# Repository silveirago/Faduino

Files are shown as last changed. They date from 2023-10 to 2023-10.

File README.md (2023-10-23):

# Faduino

The Faduino is a DIY MIDI controller inspired in the Presonus Faderport. It has one motorized fader, a rotary encoder and several silicone buttons, plus two PCBs. One PCB contains all the pads, which are triggered by the silicone buttons, addressable LEDs, a multiplexer, and some other stuff.
It can control natively any DAW, because it works with the MCU - or Mackie - Protocol, so it can work even in Pro Tools. With its motorized fader, rotary encoder, and LED buttons, you can change the track and the parameters in DAW get updated in the controller, moving the motorized fader, changing LEDs, etc.
With the Faduino you can control any channel strip, transport, and many other things in the DAW!

Complete Tutorial: Nerd Musician Pro (all the courses): https://go.musiconerd.com/nerd-musician-pro
Tutorialo Completo (Português): Fazendo Música com Arduino: https://go.musiconerd.com/fazendo-musica-com-arduino
Watch the YT video: https://youtu.be/M8krxn_5pIs

by Gustavo Silveira
gustavosilveira@musiconerd.com

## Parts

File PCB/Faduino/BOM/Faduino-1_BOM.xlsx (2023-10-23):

Comment | Designator | Footprint | LCSC Part #
100nF Unpolarized capacitor, small symbol | C1,C2,C3,C4,C5,C6,C7,C8,C9,C10,C11,C12,C13,C14,C15,C16,C17,C18,C19,C20,C21,C22,C23,C24 | C_0603_1608Metric | C14663
100nF Unpolarized capacitor, small symbol | C_mux_1,C_mux_2 | C_0603_1608Metric | C14663
100nF | C_pwr_2 | C_0603_1608Metric | C14663
L7805 Positive 1.5A 35V Linear Regulator, Fixed Output 5V, TO-220/TO-263/TO-252 | Tension_reg1 | TO-263-2 | C15077
330nF | C_pwr_1 | C_0603_1608Metric | C1615
1M Resistor, small symbol | R1 | R_0603_1608Metric | C22935
330 Resistor, small US symbol | R19 | R_0603_1608Metric | C22935
10k Resistor, small US symbol | R2,R3,R4,R5 | R_0603_1608Metric | C25804
L293DD | L293DD1 | SOP-20_7.5x12.8mm_P1.27mm | C5199946
WS2812B RGB LED with integrated controller | D2,D3,D4,D5,D6,D7,D8,D9,D10,D11,D12,D13,D14,D15,D16,D17,D18,D19,D20,D21,D22,D23,D24 | WS2812B-mini-V3-2 | C527089
WS2812B RGB LED with integrated controller | D_1 | WS2812B-mini-V3 | C527089
10nF Unpolarized capacitor, small symbol | C_enc_1,C_enc_2 | C_0603_1608Metric | C57112
1N4007 1000V 1A General Purpose Rectifier Diode, DO-41 | Diode1 | D_SMA_Handsoldering | C727081
CD74HC4067M_2 | Mux_1,Mux_2 | SSOP-24_5.3x8.2mm_P0.65mm | C97702

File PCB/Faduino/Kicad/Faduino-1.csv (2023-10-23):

Comment | Designator | Footprint | LCSC Part #
100nF Unpolarized capacitor, small symbol | C1,C2,C3,C4,C5,C6,C7,C8,C9,C10,C11,C12,C13,C14,C15,C16,C17,C18,C19,C20,C21,C22,C23,C24 | C_0603_1608Metric | C14663
10nF Unpolarized capacitor, small symbol | C_enc_1,C_enc_2 | C_0603_1608Metric | C57112
100nF Unpolarized capacitor, small symbol | C_mux_1,C_mux_2 | C_0603_1608Metric | C14663
330nF | C_pwr_1 | C_0603_1608Metric | C1615
100nF | C_pwr_2 | C_0603_1608Metric | C14663
WS2812B RGB LED with integrated controller | D2,D3,D4,D5,D6,D7,D8,D9,D10,D11,D12,D13,D14,D15,D16,D17,D18,D19,D20,D21,D22,D23,D24 | WS2812B-mini-V3-2 | C527089
WS2812B RGB LED with integrated controller | D_1 | WS2812B-mini-V3 | C527089
1N4007 1000V 1A General Purpose Rectifier Diode, DO-41 | Diode1 | D_SMA_Handsoldering | C727081
Rotary_Encoder_Switch | Encoder1 | RotaryEncoder_Alps_EC11E-Switch_Vertical_H20mm_CircularMountingHoles
Conn_01x06 Generic connector, single row, 01x06, script generated (kicad-library-utils/schlib/autogen/connector/) | Extra_pins1 | PinSocket_1x06_P2.54mm_Vertical
L293DD | L293DD1 | SOP-20_7.5x12.8mm_P1.27mm | C5199946
Conn_01x06_Female Generic connector, single row, 01x06, script generated (kicad-library-utils/schlib/autogen/connector/) | mtr_fdr1 | PinHeader_1x06_P2.54mm_Vertical
CD74HC4067M_2 | Mux_1,Mux_2 | SSOP-24_5.3x8.2mm_P0.65mm | C97702
Jack-DC DC Barrel Jack | Power_jack1 | BarrelJack_Horizontal
1M Resistor, small symbol | R1 | R_0603_1608Metric | C22935
10k Resistor, small US symbol | R2,R3,R4,R5 | R_0603_1608Metric | C25804
330 Resistor, small US symbol | R19 | R_0603_1608Metric | C22935
SW_SPST Single Pole Single Throw (SPST) switch | SW1,SW2,SW3,SW4,SW5,SW6,SW7,SW8,SW9,SW10,SW11,SW12,SW13,SW14,SW15,SW16,SW17,SW18,SW19,SW20,SW21,SW22,SW23,SW24 | BUTTONPAD-1x1
L7805 Positive 1.5A 35V Linear Regulator, Fixed Output 5V, TO-220/TO-263/TO-252 | Tension_reg1 | TO-263-2 | C15077
Arduino_Pro_Micro | U1 | ArduinoProMicro

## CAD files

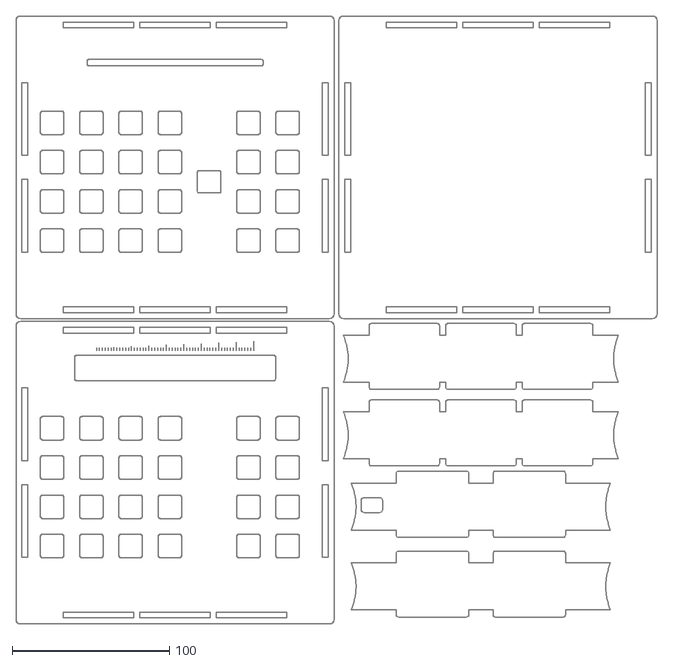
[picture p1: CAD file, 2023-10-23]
Enclosure/Faduino - 3mm.dxf
408.2 x 387.0

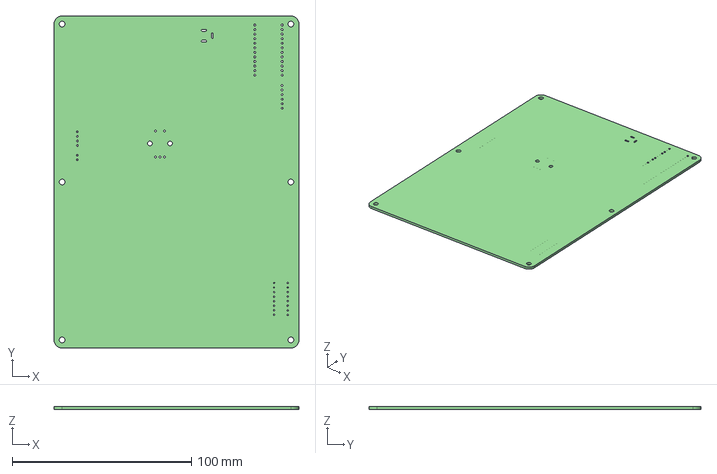
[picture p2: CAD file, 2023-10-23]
PCB/Faduino/Kicad/Faduino-1.step
136.5 x 185.0 x 1.60 mm

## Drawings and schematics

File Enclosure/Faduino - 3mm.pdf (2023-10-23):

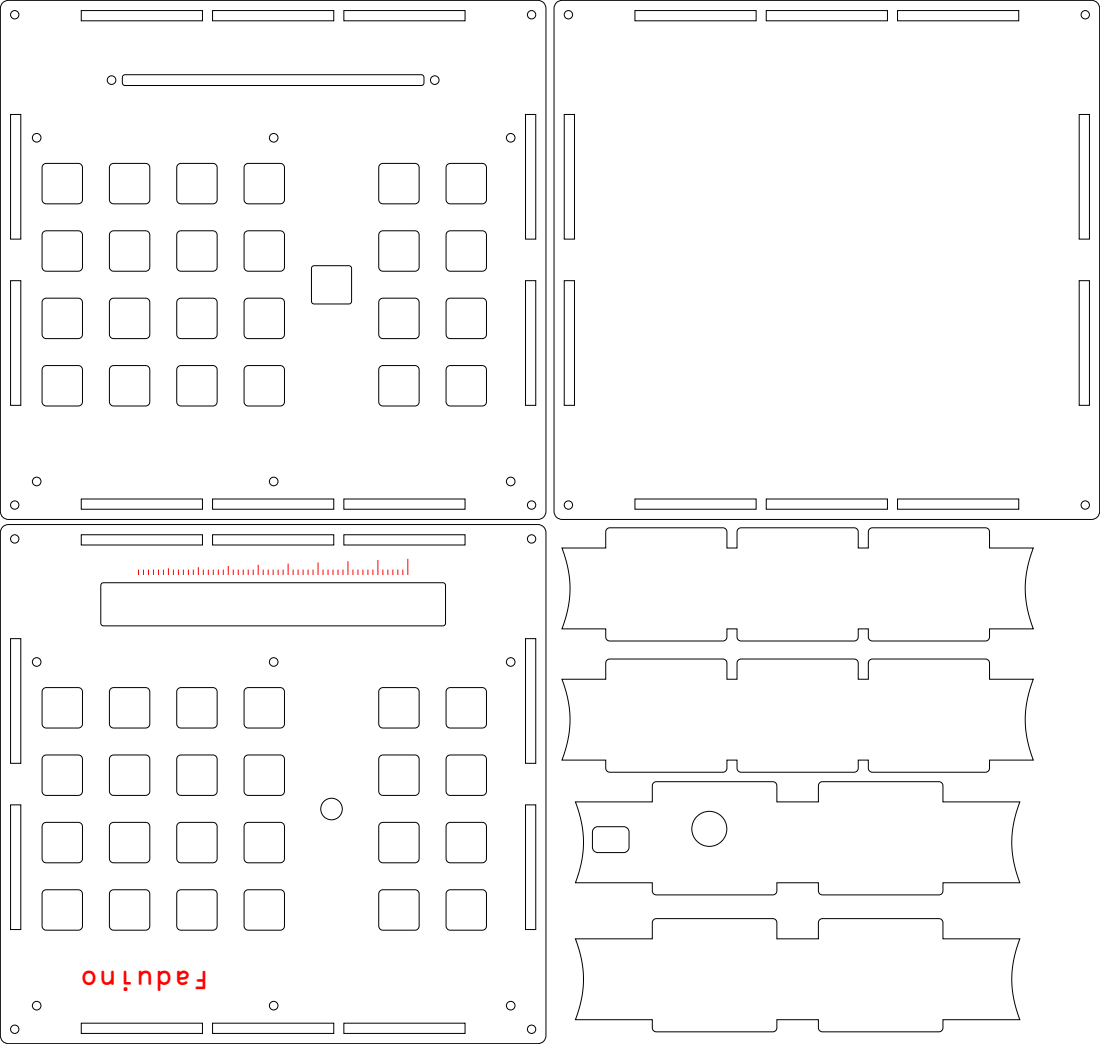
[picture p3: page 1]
Faduino

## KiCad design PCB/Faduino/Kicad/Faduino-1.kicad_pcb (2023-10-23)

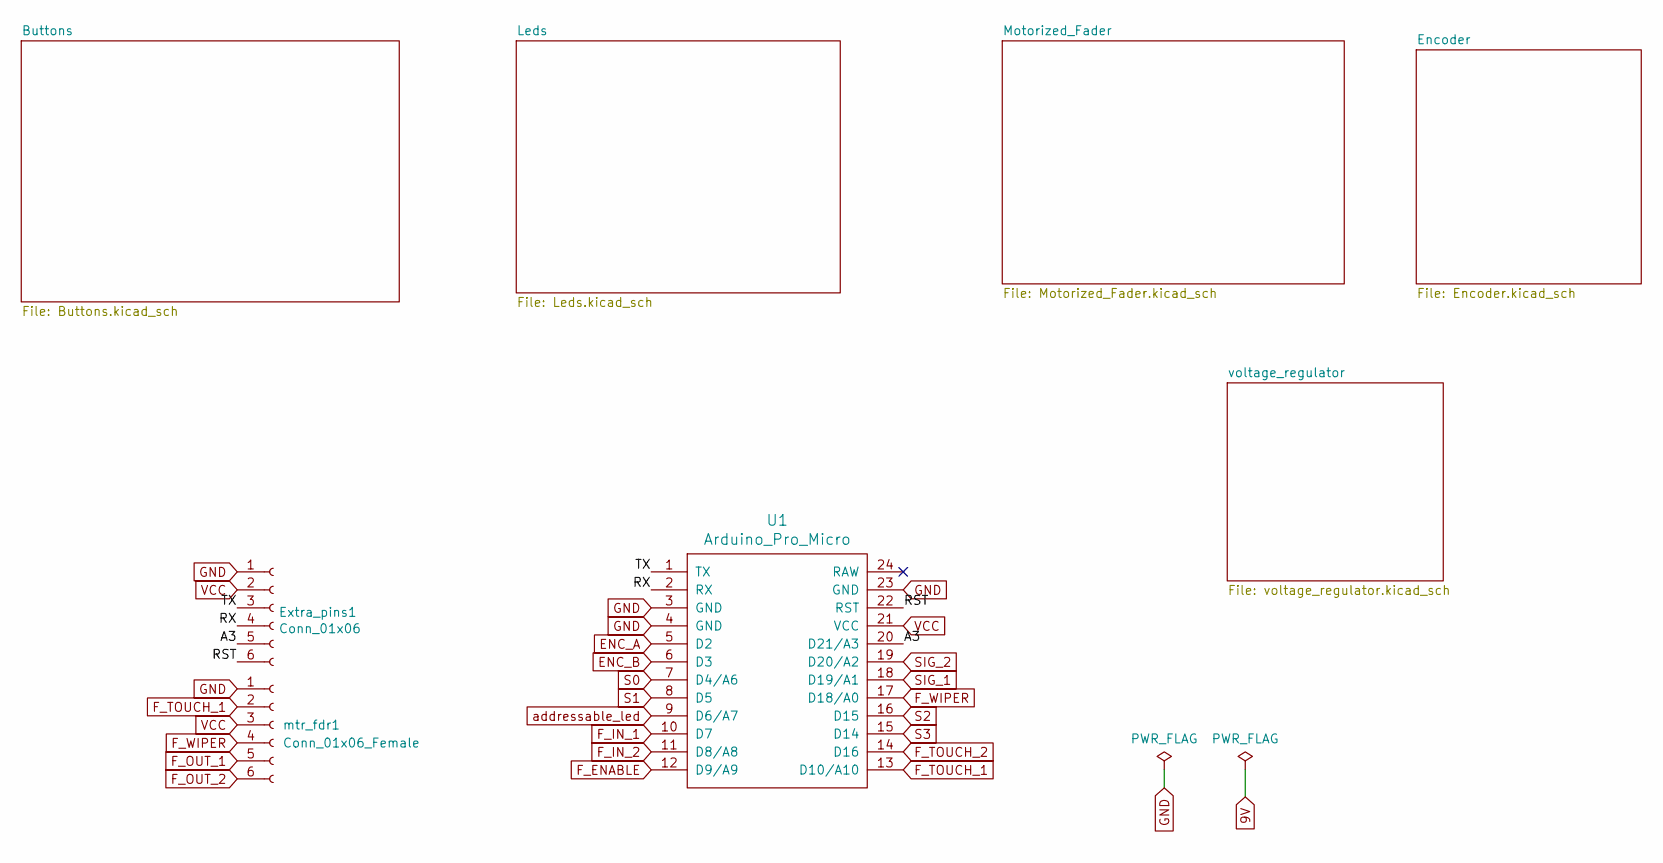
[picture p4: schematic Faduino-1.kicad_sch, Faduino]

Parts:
Extra_pins1: Conn_01x06; PinSocket_1x06_P2.54mm_Vertical
U1: Arduino_Pro_Micro; ArduinoProMicro
mtr_fdr1: Conn_01x06_Female; IDC-Header_2x03_P2.54mm_Vertical

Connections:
/A3: Extra_pins1.5, U1.20 (D21/A3)
/RST: Extra_pins1.6, U1.22 (RST)
/RX: Extra_pins1.4, U1.2 (RX)
/TX: Extra_pins1.3, U1.1 (TX)
ENC_A: U1.5 (D2); also elsewhere on the board
ENC_B: U1.6 (D3); also elsewhere on the board
F_ENABLE: U1.12 (D9/A9); also elsewhere on the board
F_IN_1: U1.10 (D7); also elsewhere on the board
F_IN_2: U1.11 (D8/A8); also elsewhere on the board
F_TOUCH_1: U1.13 (D10/A10), mtr_fdr1.2; also elsewhere on the board
F_TOUCH_2: U1.14 (D16); also elsewhere on the board
F_WIPER: U1.17 (D18/A0), mtr_fdr1.4; also elsewhere on the board
GND: Extra_pins1.1, U1.3 (GND), U1.4 (GND), U1.23 (GND), mtr_fdr1.1; also elsewhere on the board
S0: U1.7 (D4/A6); also elsewhere on the board
S1: U1.8 (D5); also elsewhere on the board
S2: U1.16 (D15); also elsewhere on the board
S3: U1.15 (D14); also elsewhere on the board
SIG_1: U1.18 (D19/A1); also elsewhere on the board
SIG_2: U1.19 (D20/A2); also elsewhere on the board
VCC: Extra_pins1.2, U1.21 (VCC), mtr_fdr1.3; also elsewhere on the board
addressable_led: U1.9 (D6/A7); also elsewhere on the board

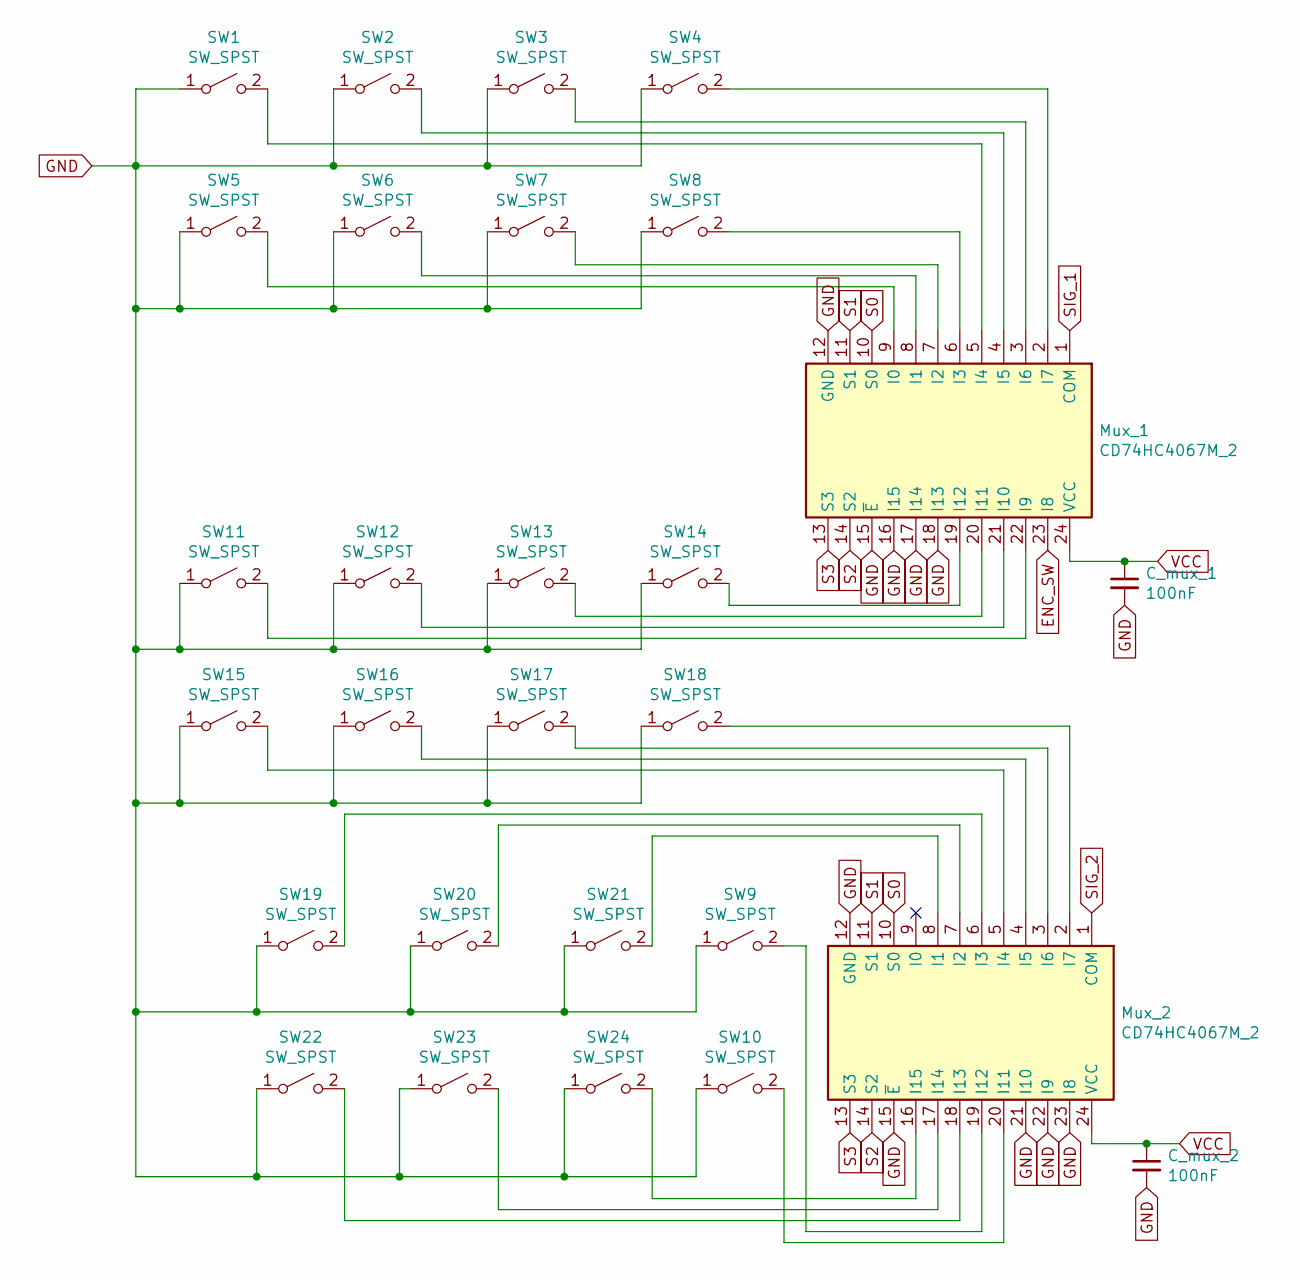
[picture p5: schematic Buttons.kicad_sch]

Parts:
C_mux_1, C_mux_2: 100nF; C_0603_1608Metric; LCSC Part Number C14663
Mux_1, Mux_2: CD74HC4067M_2; SSOP-24_5.3x8.2mm_P0.65mm; LCSC Part Number C98457
SW1, SW2, SW3, SW4, SW5, SW6, SW7, SW8, SW9, SW10, SW11, SW12, SW13, SW14, SW15, SW16, SW17, SW18, SW19, SW20, SW21, SW22, SW23, SW24: SW_SPST; BUTTONPAD-1x1

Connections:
ENC_SW: Mux_1.23 (I8); also elsewhere on the board
GND: C_mux_1.2, C_mux_2.2, Mux_1.12 (GND), Mux_1.15 (~E), Mux_1.16 (I15), Mux_1.17 (I14), Mux_1.18 (I13), Mux_2.12 (GND), Mux_2.15 (~E), Mux_2.21 (I10), Mux_2.22 (I9), Mux_2.23 (I8), SW1.1 (A), SW2.1 (A), SW3.1 (A), SW4.1 (A), SW5.1 (A), SW6.1 (A), SW7.1 (A), SW8.1 (A), SW9.1 (A), SW10.1 (A), SW11.1 (A), SW12.1 (A), SW13.1 (A), SW14.1 (A), SW15.1 (A), SW16.1 (A), SW17.1 (A), SW18.1 (A), SW19.1 (A), SW20.1 (A), SW21.1 (A), SW22.1 (A), SW23.1 (A), SW24.1 (A); also elsewhere on the board
unnamed: Mux_1.2 (I7), SW4.2 (B)
unnamed: Mux_1.3 (I6), SW3.2 (B)
unnamed: Mux_1.4 (I5), SW2.2 (B)
unnamed: Mux_1.5 (I4), SW1.2 (B)
unnamed: Mux_1.6 (I3), SW8.2 (B)
unnamed: Mux_1.7 (I2), SW7.2 (B)
unnamed: Mux_1.8 (I1), SW6.2 (B)
unnamed: Mux_1.9 (I0), SW5.2 (B)
unnamed: Mux_1.19 (I12), SW14.2 (B)
unnamed: Mux_1.20 (I11), SW13.2 (B)
unnamed: Mux_1.21 (I10), SW12.2 (B)
unnamed: Mux_1.22 (I9), SW11.2 (B)
unnamed: Mux_2.2 (I7), SW18.2 (B)
unnamed: Mux_2.3 (I6), SW17.2 (B)
unnamed: Mux_2.4 (I5), SW16.2 (B)
unnamed: Mux_2.5 (I4), SW15.2 (B)
unnamed: Mux_2.6 (I3), SW19.2 (B)
unnamed: Mux_2.7 (I2), SW20.2 (B)
unnamed: Mux_2.8 (I1), SW21.2 (B)
unnamed: Mux_2.16 (I15), SW24.2 (B)
unnamed: Mux_2.17 (I14), SW23.2 (B)
unnamed: Mux_2.18 (I13), SW22.2 (B)
unnamed: Mux_2.19 (I12), SW9.2 (B)
unnamed: Mux_2.20 (I11), SW10.2 (B)
S0: Mux_1.10 (S0), Mux_2.10 (S0); also elsewhere on the board
S1: Mux_1.11 (S1), Mux_2.11 (S1); also elsewhere on the board
S2: Mux_1.14 (S2), Mux_2.14 (S2); also elsewhere on the board
S3: Mux_1.13 (S3), Mux_2.13 (S3); also elsewhere on the board
SIG_1: Mux_1.1 (COM); also elsewhere on the board
SIG_2: Mux_2.1 (COM); also elsewhere on the board
VCC: C_mux_1.1, C_mux_2.1, Mux_1.24 (VCC), Mux_2.24 (VCC); also elsewhere on the board

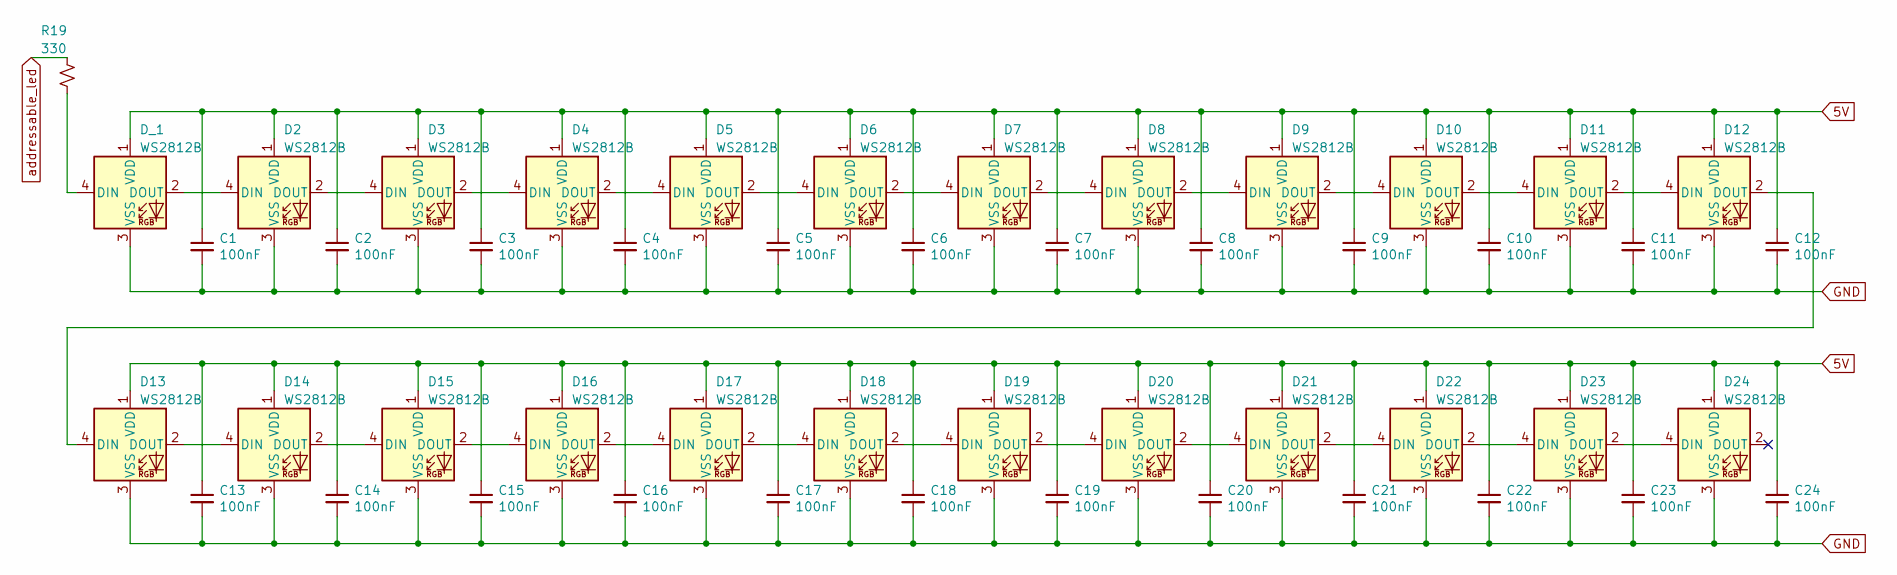
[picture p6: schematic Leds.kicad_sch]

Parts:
C1, C2, C3, C4, C5, C6, C7, C8, C9, C10, C11, C12, C13, C14, C15, C16, C17, C18, C19, C20, C21, C22, C23, C24: 100nF; C_0603_1608Metric; LCSC Part Number C14663
D2, D3, D4, D5, D6, D7, D8, D9, D10, D11, D12, D13, D14, D15, D16, D17, D18, D19, D20, D21, D22, D23, D24: WS2812B; WS2812B-mini-V3-2; LCSC Part Number C114583
D_1: WS2812B; WS2812B-mini-V3; LCSC Part Number C114583
R19: 330; R_0603_1608Metric; LCSC Part Number C23138

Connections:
5V: C1.1, C2.1, C3.1, C4.1, C5.1, C6.1, C7.1, C8.1, C9.1, C10.1, C11.1, C12.1, C13.1, C14.1, C15.1, C16.1, C17.1, C18.1, C19.1, C20.1, C21.1, C22.1, C23.1, C24.1, D2.1 (VDD), D3.1 (VDD), D4.1 (VDD), D5.1 (VDD), D6.1 (VDD), D7.1 (VDD), D8.1 (VDD), D9.1 (VDD), D10.1 (VDD), D11.1 (VDD), D12.1 (VDD), D13.1 (VDD), D14.1 (VDD), D15.1 (VDD), D16.1 (VDD), D17.1 (VDD), D18.1 (VDD), D19.1 (VDD), D20.1 (VDD), D21.1 (VDD), D22.1 (VDD), D23.1 (VDD), D24.1 (VDD), D_1.1 (VDD); also elsewhere on the board
GND: C1.2, C2.2, C3.2, C4.2, C5.2, C6.2, C7.2, C8.2, C9.2, C10.2, C11.2, C12.2, C13.2, C14.2, C15.2, C16.2, C17.2, C18.2, C19.2, C20.2, C21.2, C22.2, C23.2, C24.2, D2.3 (VSS), D3.3 (VSS), D4.3 (VSS), D5.3 (VSS), D6.3 (VSS), D7.3 (VSS), D8.3 (VSS), D9.3 (VSS), D10.3 (VSS), D11.3 (VSS), D12.3 (VSS), D13.3 (VSS), D14.3 (VSS), D15.3 (VSS), D16.3 (VSS), D17.3 (VSS), D18.3 (VSS), D19.3 (VSS), D20.3 (VSS), D21.3 (VSS), D22.3 (VSS), D23.3 (VSS), D24.3 (VSS), D_1.3 (VSS); also elsewhere on the board
unnamed: D2.2 (DOUT), D3.4 (DIN)
unnamed: D2.4 (DIN), D_1.2 (DOUT)
unnamed: D3.2 (DOUT), D4.4 (DIN)
unnamed: D4.2 (DOUT), D5.4 (DIN)
unnamed: D5.2 (DOUT), D6.4 (DIN)
unnamed: D6.2 (DOUT), D7.4 (DIN)
unnamed: D7.2 (DOUT), D8.4 (DIN)
unnamed: D8.2 (DOUT), D9.4 (DIN)
unnamed: D10.2 (DOUT), D11.4 (DIN)
unnamed: D9.2 (DOUT), D10.4 (DIN)
unnamed: D11.2 (DOUT), D12.4 (DIN)
unnamed: D12.2 (DOUT), D13.4 (DIN)
unnamed: D13.2 (DOUT), D14.4 (DIN)
unnamed: D14.2 (DOUT), D15.4 (DIN)
unnamed: D15.2 (DOUT), D16.4 (DIN)
unnamed: D16.2 (DOUT), D17.4 (DIN)
unnamed: D17.2 (DOUT), D18.4 (DIN)
unnamed: D18.2 (DOUT), D19.4 (DIN)
unnamed: D19.2 (DOUT), D20.4 (DIN)
unnamed: D20.2 (DOUT), D21.4 (DIN)
unnamed: D21.2 (DOUT), D22.4 (DIN)
unnamed: D22.2 (DOUT), D23.4 (DIN)
unnamed: D23.2 (DOUT), D24.4 (DIN)
unnamed: D_1.4 (DIN), R19.2
addressable_led: R19.1; also elsewhere on the board

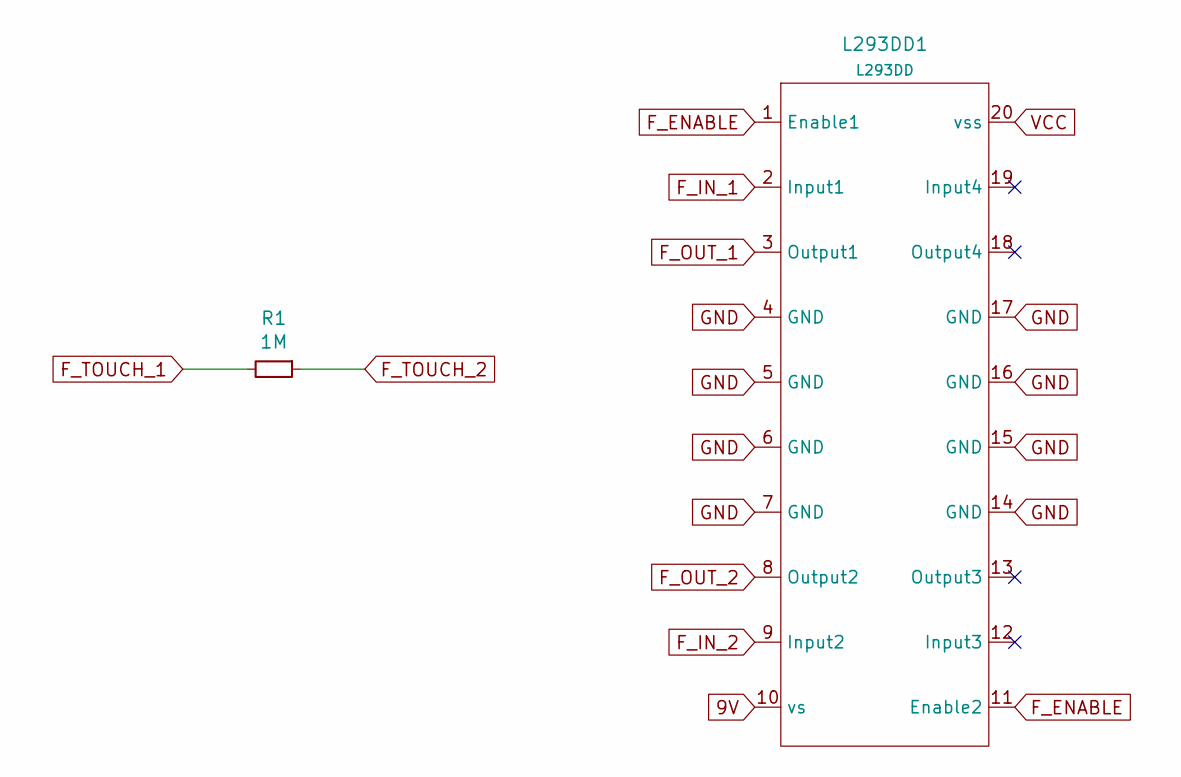
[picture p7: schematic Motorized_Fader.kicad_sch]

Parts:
L293DD1: L293DD; SOP-20_7.5x12.8mm_P1.27mm; LCSC C5199946
R1: 1M; R_0603_1608Metric; LCSC Part Number C22935

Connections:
9V: L293DD1.10 (vs); also elsewhere on the board
F_ENABLE: L293DD1.1 (Enable1), L293DD1.11 (Enable2); also elsewhere on the board
F_IN_1: L293DD1.2 (Input1); also elsewhere on the board
F_IN_2: L293DD1.9 (Input2); also elsewhere on the board
F_OUT_1: L293DD1.3 (Output1); also elsewhere on the board
F_OUT_2: L293DD1.8 (Output2); also elsewhere on the board
F_TOUCH_1: R1.2; also elsewhere on the board
F_TOUCH_2: R1.1; also elsewhere on the board
GND: L293DD1.4 (GND), L293DD1.5 (GND), L293DD1.6 (GND), L293DD1.7 (GND), L293DD1.14 (GND), L293DD1.15 (GND), L293DD1.16 (GND), L293DD1.17 (GND); also elsewhere on the board
VCC: L293DD1.20 (vss); also elsewhere on the board

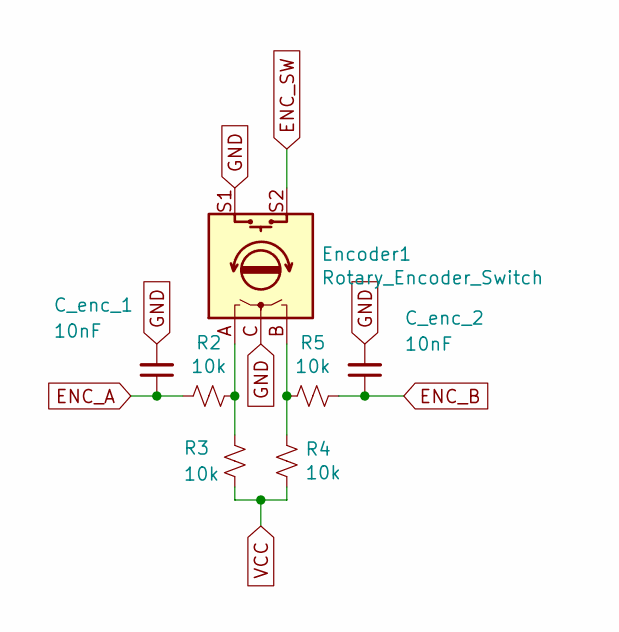
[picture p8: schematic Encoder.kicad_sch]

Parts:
C_enc_1, C_enc_2: 10nF; C_0603_1608Metric; LCSC Part Number C57112
Encoder1: Rotary_Encoder_Switch; RotaryEncoder_Alps_EC11E-Switch_Vertical_H20mm_CircularMoun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
R2, R3, R4, R5: 10k; R_0603_1608Metric; LCSC Part Number C25804

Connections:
ENC_A: C_enc_1.1, R2.2; also elsewhere on the board
ENC_B: C_enc_2.1, R5.1; also elsewhere on the board
ENC_SW: Encoder1.S2; also elsewhere on the board
GND: C_enc_1.2, C_enc_2.2, Encoder1.C, Encoder1.S1; also elsewhere on the board
unnamed: Encoder1.A, R2.1, R3.1
unnamed: Encoder1.B, R4.1, R5.2
VCC: R3.2, R4.2; also elsewhere on the board

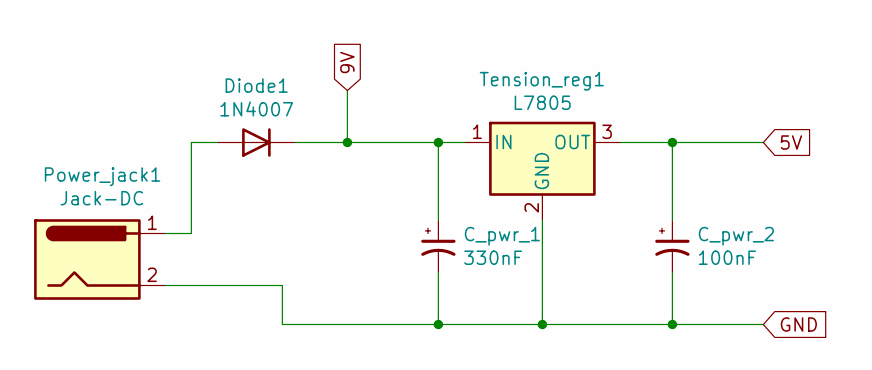
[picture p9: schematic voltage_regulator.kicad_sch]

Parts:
C_pwr_1: 330nF; C_0603_1608Metric; LCSC Part Number C1615
C_pwr_2: 100nF; C_0603_1608Metric; LCSC Part Number C14663
Diode1: 1N4007; D_SMA_Handsoldering; LCSC Part Number C727081
Power_jack1: Jack-DC; BarrelJack_Horizontal
Tension_reg1: L7805; TO-263-2; LCSC C310413

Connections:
5V: C_pwr_2.1, Tension_reg1.3 (OUT); also elsewhere on the board
9V: C_pwr_1.1, Diode1.1 (K), Tension_reg1.1 (IN); also elsewhere on the board
GND: C_pwr_1.2, C_pwr_2.2, Power_jack1.2, Tension_reg1.2 (GND); also elsewhere on the board
unnamed: Diode1.2 (A), Power_jack1.1

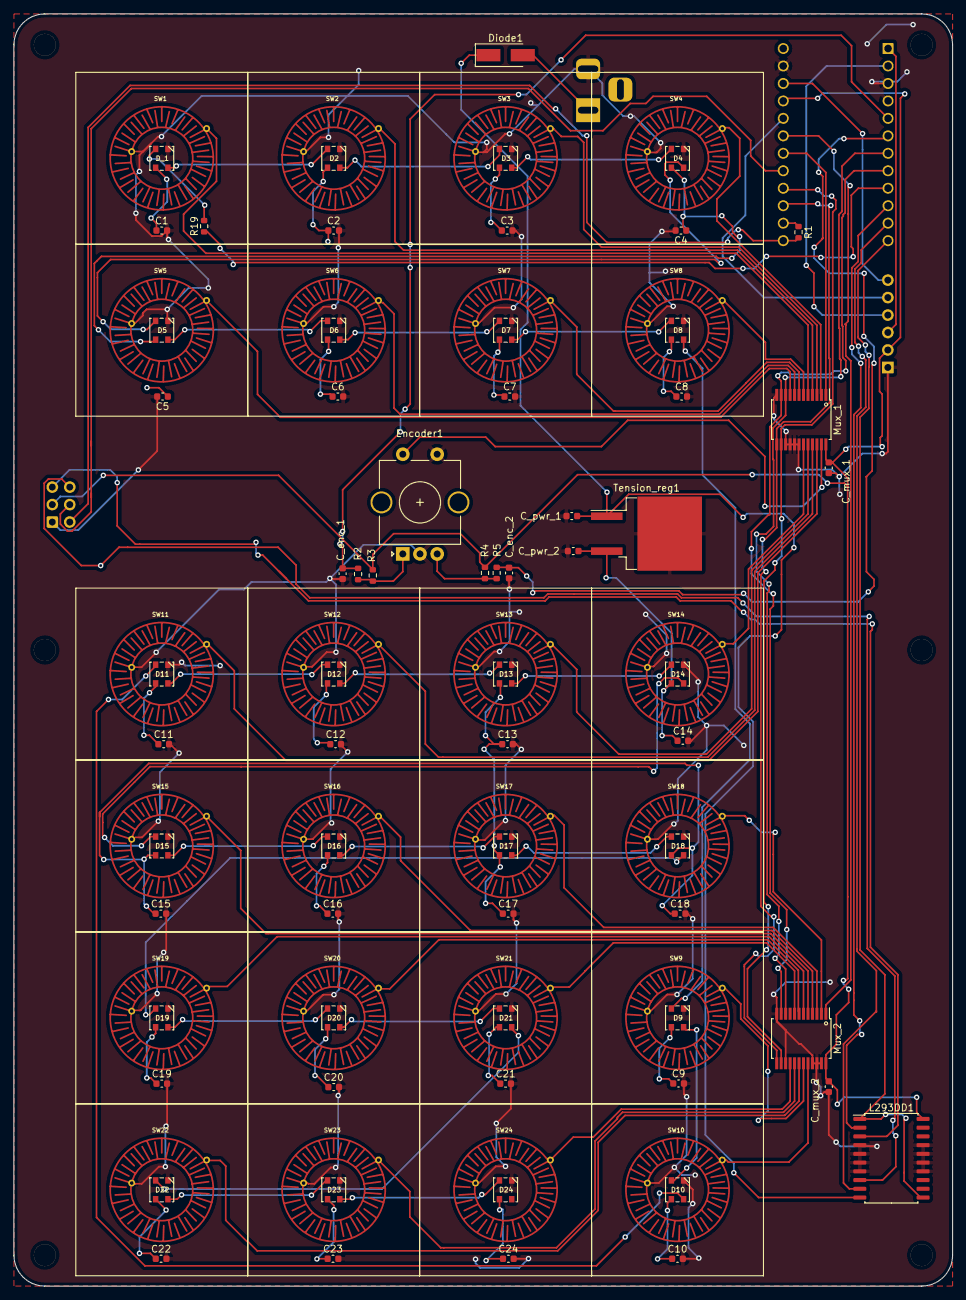
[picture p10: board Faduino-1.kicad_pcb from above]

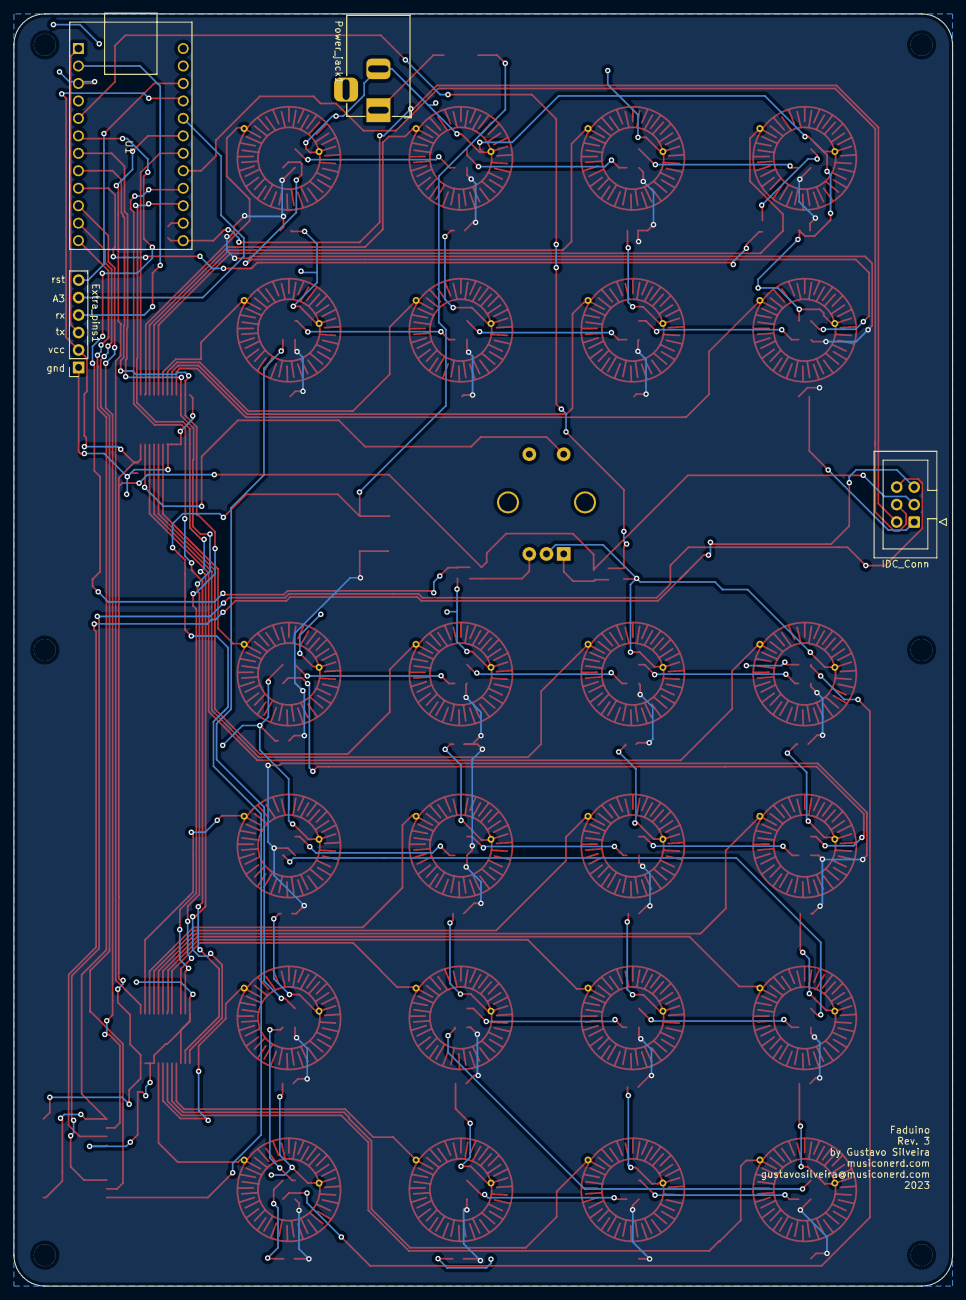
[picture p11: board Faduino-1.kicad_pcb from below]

Board: 2 copper layers, 136.5 x 185.0 mm, 94 parts (4 on the bottom side), 77 nets.

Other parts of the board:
IDC_Conn: Conn_01x06_Female; IDC-Header_2x03_P2.54mm_Vertical

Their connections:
F_OUT_1: IDC_Conn.5; also elsewhere on the board
F_OUT_2: IDC_Conn.6; also elsewhere on the board
F_TOUCH_1: IDC_Conn.2; also elsewhere on the board
F_WIPER: IDC_Conn.4; also elsewhere on the board
GND: IDC_Conn.1; also elsewhere on the board
VCC: IDC_Conn.3; also elsewhere on the board

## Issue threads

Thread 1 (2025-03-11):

Build cost and part sourcing

iamjonny, 2025-03-11:
This is amazing. I have an Arduino and a breadboard , for testing and development I hope to get the parts required to have a motorised pot (rotary encoder?)
and maybe a fader too..

Soldering is something I hope can be mastered with practice!

Where do you get the silicon buttons and the box? I tried following the first link to get the board for this project but appeared to have option on 1-6 boards and much much more.

Is this available to purchase as a buildable, eg with all required parts, or even pre built?

Thanks!

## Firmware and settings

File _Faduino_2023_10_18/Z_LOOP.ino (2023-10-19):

void loop() {

  // Serial.println(faderMin[0]);
  // Serial.println(faderMax[0]);

#ifdef ATMEGA32U4

  // it will read MIDI incoming messages if using ATMEGA32U4
  MIDIread();

#endif

#ifdef TEENSY

  // usbMIDI.read() needs to be called rapidly from loop().  When
  // each MIDI messages arrives, it return true.  The message must
  // be fully processed before usbMIDI.read() is called again.
  if (usbMIDI.read()) {
    processMIDI();
  }

#endif

#ifdef USING_BUTTONS

  // Get the current time
  unsigned long buttonsCurrentMillis = millis();

  // Check if it's time to run the function
  if (buttonsCurrentMillis - buttonsPreviousMillis >= buttonsInterval) {
    // Save the last time the function was run
    buttonsPreviousMillis = buttonsCurrentMillis;
    // Call your function here
    buttons();
  }

#endif

#ifdef USING_POTENTIOMETERS
  potentiometers();
#endif

#ifdef USING_ENCODER
  encoders();
  isEncoderMoving();

#endif

/////////////////////////////////////////////
// MOTORIZED FADERS
#ifdef USING_MOTORIZED_FADERS

  for (int i = 0; i < N_M_FADERS; i++) {

    touchLine[i] = capSense[i].capacitiveSensor(capSenseSpeed);
    checkTouch(i, touchLine[i]);

    int reading = analogRead(POT_ARDUINO_PIN[i]);
    responsivePot[i].update(reading);
    potCState[i] = responsivePot[i].getValue();

    //int val = abs(actualPos - potCState[i]);

    updateFader(i, faderPos[i]);

    //     if (val != prevMtrVal || recevingMidi == true) {
    //       updateFader(i, faderPos[i]);

    // #ifdef DEBUG
    //       Serial.print("i: ");
    //       Serial.print(i);
    //       Serial.print(", potCState: ");
    //       Serial.print(potCState[i]);
    //       Serial.print(", actualPos: ");
    //       Serial.print(actualPos);
    //       Serial.print(", val: ");
    //       Serial.println(val);
    // #endif

    //       prevMtrVal = val;
    //     }
  }

#endif  // USING_MOTORIZED_FADERS
}

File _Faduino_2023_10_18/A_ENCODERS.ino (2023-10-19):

/////////////////////////////////////////////
// ENCODERS

#ifdef USING_ENCODER  // only happens if encoders are defined in the setup


/////////////////////////////////////////////
// variables you don't need to change

int lastEncoderValue[N_ENCODER_MIDI_CHANNELS][N_ENCODERS] = { 0 };
int lastEncoderMidiValue[N_ENCODER_MIDI_CHANNELS][N_ENCODERS] = { 0 };
int encoderValue[N_ENCODER_MIDI_CHANNELS][N_ENCODERS] = { 0 };
int encoderMidiValue[N_ENCODER_MIDI_CHANNELS][N_ENCODERS] = { 0 };
int encoderMackieValue[N_ENCODER_MIDI_CHANNELS][N_ENCODERS] = { 0 };
boolean turningCW = false;

// for the encoder Channels - Used for different banks

byte lastEncoderChannel = 0;

unsigned long encPTime[N_ENCODERS] = { 0 };
unsigned long encTimer[N_ENCODERS] = { 0 };
boolean encMoving[N_ENCODERS] = { false };
boolean encMoved[N_ENCODERS] = { false };
byte encTIMEOUT = 50;
byte encoder_n;
float encTempVal = 0;

#ifdef USING_HIGH_RES_ENC
// Use this to send CC using 2 bytes (14 bit res)
unsigned int highResenc[N_ENCODER_MIDI_CHANNELS][N_ENCODERS] = { 0 };  // stores the high res val
byte encMSB[N_ENCODER_MIDI_CHANNELS][N_ENCODERS] = { 0 };              // Most Significant Byte
byte encLSB[N_ENCODER_MIDI_CHANNELS][N_ENCODERS] = { 0 };              // Least Significant Byte
byte pencLSB[N_ENCODER_MIDI_CHANNELS][N_ENCODERS] = { 0 };             // Previous Most Significant Byte
#endif

/////////////////////////////////////////////
// Function
void encoders() {


  for (int i = 0; i < N_ENCODERS; i++) {

    int encoderValueTemp = encoder[i].read();  // reads each encoder and stores the value
    // Serial.print("Raw Encoder Value: ");
    // Serial.println(encoderValueTemp);
    encoderValue[ENCODER_MIDI_CH][i] = encoderValueTemp;

#if !defined(TRAKTOR) && !defined(USING_MACKIE)  // if not defined traktor or Mackie
    //#ifndef TRAKTOR // if not def Traktor
    //#ifndef USING_MACKIE
    clipEncoderValue(i, encoderMinVal, encoderMaxVal * encSensitivity);  // checks if it's greater than the max value or less than the min value
                                                                         //#endif

#endif

    // USING HIGH RES ENCODERS
#ifdef USING_HIGH_RES_ENC  // if def

    highResenc[ENCODER_MIDI_CH][i] = map(encoderValue[ENCODER_MIDI_CH][i], 0, encoderMaxVal * encSensitivity, 0, encoderMaxVal);  // changes the enconder sensitivity
    encMSB[ENCODER_MIDI_CH][i] = highResenc[ENCODER_MIDI_CH][i] / 128;                                                            // Most Sigficant Byte
    encLSB[ENCODER_MIDI_CH][i] = highResenc[ENCODER_MIDI_CH][i] % 128;                                                            // Least Significant Byte

#endif  // USING_HIGH_RES_ENC

    encoderMidiValue[ENCODER_MIDI_CH][i] = map(encoderValue[ENCODER_MIDI_CH][i], encoderMinVal, encoderMaxVal * encSensitivity, 0, encoderMaxVal);  // changes the enconder sensitivity
  }

  for (int i = 0; i < N_ENCODERS; i++) {

    if (!encMoving[i]) {


      if (encoderMidiValue[ENCODER_MIDI_CH][i] != lastEncoderMidiValue[ENCODER_MIDI_CH][i]) {

        encoderSendMIDI(i);
      }
    }
  }
}


////////////////////////////////////////////
// checks if it's greater than maximum value or less than then the minimum value
void clipEncoderValue(int i, int minVal, int maxVal) {

  if (encoderValue[ENCODER_MIDI_CH][i] > maxVal - 1) {
    encoderValue[ENCODER_MIDI_CH][i] = maxVal;
    //Serial.println(encoderValue[ENCODER_MIDI_CH][i]);
    encoder[i].write(maxVal);
  }
  if (encoderValue[ENCODER_MIDI_CH][i] < minVal + 1) {
    encoderValue[ENCODER_MIDI_CH][i] = minVal;
    //Serial.println(encoderValue[ENCODER_MIDI_CH][i]);
    encoder[i].write(minVal);
  }
}

/* When receiving MIDI from the daw the encoder updates itself and send midi back
  this causes some sort of feedack. This function prevents the encoder to update itself
  unti it stopped receiving midi from the daw.
*/
void isEncoderMoving() {

  for (int i = 0; i < N_ENCODERS; i++) {

    if (encMoved[i] == true) {

      encPTime[i] = millis();  // Stores the previous time
    }

    encTimer[i] = millis() - encPTime[i];  // Resets the encTimer 11000 - 11000 = 0ms

    if (encTimer[i] < encTIMEOUT) {  // If the encTimer is less than the maximum allowed time it means that the encoder is still moving
      encMoving[i] = true;
      encMoved[i] = false;

    } else {

      if (encMoving[i] == true) {

        encMoving[i] = false;
      }
    }
  }
}

void encoderSendMIDI(byte i) {

#ifdef TRAKTOR  // to use with Traktor
  if (encoderValue[ENCODER_MIDI_CH][i] > lastEncoderValue[ENCODER_MIDI_CH][i]) {
    encoderMidiValue[ENCODER_MIDI_CH][i] = 127;
    //encoder[i].write(127);
  } else {
    encoderMidiValue[ENCODER_MIDI_CH][i] = 0;
    //encoder[i].write(0);
  }
#endif  // TRAKTOR

  // - - - - - - - - - - - - - - - - - - - - - - - - - - - -

#ifdef USING_MACKIE  // to use with Mackie
  if (encoderValue[ENCODER_MIDI_CH][i] > lastEncoderValue[ENCODER_MIDI_CH][i]) {
    encoderMackieValue[ENCODER_MIDI_CH][i] = 0 + encoderSens;
    turningCW = false;
  } else {
    encoderMackieValue[ENCODER_MIDI_CH][i] = 64 + encoderSens;
    turningCW = true;
  }
#endif


  // - - - - - - - - - - - - - - - - - - - - - - - - - - - -

  //clipEncoderValue(i, encoderMinVal, encoderMaxVal); // checks if it's greater than the max value or less than the min value

  // Sends the MIDI CC accordingly to the chosen board

  // - - - - - - - - - - - - - - - - - - - - - - - - - - - -

#ifdef ATMEGA32U4
  // if using with ATmega32U4 (micro, pro micro, leonardo...)

#ifdef USING_MACKIE  // to use with Mackie

  // MOTORIZED FADER
  switch (encoderSelect) {
    case 0:                                                                                     // PAN                                                                                 // PAN
      controlChange(ENCODER_MIDI_CH, ENCODER_CC_N[i], encoderMackieValue[ENCODER_MIDI_CH][i]);  //  (channel, CC number,  CC value)
      MidiUSB.flush();
      break;

    case 1:                                                                        // SCROLL                                                                        // SCROLL
      controlChange(ENCODER_MIDI_CH, 60, encoderMackieValue[ENCODER_MIDI_CH][i]);  //  (channel, CC number,  CC value)
      MidiUSB.flush();
      break;

    case 2:  // CHANGE TRACK


      if (turningCW == true) {
        noteOn(BUTTON_MIDI_CH, LEFT, 127);
        noteOff(BUTTON_MIDI_CH, LEFT, 127);
        MidiUSB.flush();
        break;
      } else {
        noteOn(BUTTON_MIDI_CH, RIGHT, 127);
        noteOff(BUTTON_MIDI_CH, RIGHT, 127);
        MidiUSB.flush();
        break;
      }
  }

#elif USING_HIGH_RES_ENC  // if def

  controlChange(ENCODER_MIDI_CH, ENCODER_CC_N[i], encMSB[ENCODER_MIDI_CH][i]);  //  (channel, CC number,  CC value)
  MidiUSB.flush();
  controlChange(ENCODER_MIDI_CH, ENCODER_CC_N[i] + 32, encLSB[ENCODER_MIDI_CH][i]);  //  (channel, CC number,  CC value)
  MidiUSB.flush();
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

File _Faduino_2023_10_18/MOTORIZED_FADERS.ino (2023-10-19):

#ifdef USING_MOTORIZED_FADERS

int faderVar;
int faderStartPos[N_M_FADERS] = {};
int faderMidiValue[N_M_FADERS] = {};
unsigned long previousMillis = 0;    // Store the last time the function was called
const unsigned long interval = 200;  // The interval in milliseconds
//long actualPos = 0;
//int prevMtrVal = 0;

boolean wasTouched[N_M_FADERS] = { true };

//int prevMtrVal, actualPos;


/////////////////////////////////////////////
// Functions

void calibrateFader(byte i) {

  int reading;

  //Send fader to the top and read max pos_ition
  digitalWrite(motorUpPin[i], HIGH);
  delay(500);
  digitalWrite(motorUpPin[i], LOW);

  reading = analogRead(POT_ARDUINO_PIN[i]);
  responsivePot[i].update(reading);
  potCState[i] = responsivePot[i].getValue();

  delay(500);

  faderMax = potCState[i];

  Serial.print("potCState Max: ");
  Serial.println(potCState[i]);

  //Send fader to the bottom and read max pos_ition
  digitalWrite(motorDownPin[i], HIGH);
  delay(500);
  digitalWrite(motorDownPin[i], LOW);

  reading = analogRead(POT_ARDUINO_PIN[i]);
  responsivePot[i].update(reading);
  potCState[i] = responsivePot[i].getValue();

  Serial.print("potCState Min: ");
  Serial.println(potCState[i]);

  delay(500);

  faderMin = potCState[i];

#ifdef DEBUG
  Serial.print("Fader: ");
  Serial.print(i);
  Serial.print(" | min: ");
  Serial.print(faderMin);
  Serial.print(" | max: ");
  Serial.println(faderMax);
  Serial.println();
#endif

  delay(1000);
}


void checkTouch(byte i, long in_) {
  boolean isTouchTemp = (in_ > capSensitivity) ? true : false;
  isTouched[i] = isTouchTemp;

  // Check for touch state change
  if (isTouched[i] != wasTouched[i]) {
    if (isTouched[i]) {
      // Finger is touched
      // Add your code to send "1" one time here

#ifdef ATMEGA32U4
      noteOn(BUTTON_MIDI_CH, FADER_TOUCH_1, 127);  // channel, note, velocity - sends fader touch
      MidiUSB.flush();
#endif

    } else {

#ifdef ATMEGA32U4
      noteOn(BUTTON_MIDI_CH, FADER_TOUCH_1, 0);  // channel, note, velocity
      MidiUSB.flush();
#endif
    }
    wasTouched[i] = isTouched[i];

#ifdef DEBUG
    Serial.print("isTouched ");
    Serial.print(i);
    Serial.print(": ");
    Serial.println(isTouched[i]);
#endif
  }
}


// changes the position of the motorized fader
void updateFader(byte i, int pos_) {

  int reading = analogRead(POT_ARDUINO_PIN[i]);
  responsivePot[i].update(reading);
  potCState[i] = responsivePot[i].getValue();

  // Calculate the error (difference between desired and current position)
  float error = pos_ - potCState[i];

  // Calculate motor speed based on the error
  float speed = map(abs(error), faderMin, faderMax, faderSpeedMin, faderSpeedMax);  // Map error to speed range
  // Serial.println(abs(error));

  // Ensure the motor speed doesn't drop below the minimum speed
  speed = max(speed, faderSpeedMin);

  // Check if the fader is touched
  if (isTouched[i]) {
    // Stop the motor and do not move it if touched
    digitalWrite(motorUpPin[i], LOW);
    digitalWrite(motorDownPin[i], LOW);
    analogWrite(faderSpeedPin[i], 0);
  } else {


    if (faderPos[i] != faderPPos[i]) {

      faderPPos[i] = faderPos[i];
    }

    // Determine the motor direction
    if (error > 0) {
      digitalWrite(motorUpPin[i], HIGH);
      digitalWrite(motorDownPin[i], LOW);

    } else if (error < 0) {
      digitalWrite(motorUpPin[i], LOW);
      digitalWrite(motorDownPin[i], HIGH);

    } else {
      digitalWrite(motorUpPin[i], LOW);
      digitalWrite(motorDownPin[i], LOW);
      speed = 0;  // Stop the motor if error is zero
    }

    // Set the motor speed
    analogWrite(faderSpeedPin[i], speed);

    // Check if the fader is at the desired position
    if (abs(error) <= motorStopPoint) {
      // Stop the motor
      analogWrite(faderSpeedPin[i], 0);
    }
  }
}




#endif  // USING_MOTORIZED_FADERS
